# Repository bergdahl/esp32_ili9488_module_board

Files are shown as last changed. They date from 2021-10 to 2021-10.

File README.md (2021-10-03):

# esp32_ili9488_module_board

> This is a work in progress. 

This is a simple ESP32 based board for the _3.5" TFT SPI 480X320_ module. It is powered by 5V over a 
micro USB connector, and has footprints both for ESP-WROOM-32 and ESP_VROVER-32.

I designed the board primarily for use with [Dustin Watt's FreeTouchDeck firmware](https://github.com/DustinWatts/FreeTouchDeck).

Programming is done using an external FTDI232 board.

## PCB files

I have added the Gerber files in the `PCB/Gerber` folder, just zip and upload to your favorite PCB manufacturer.

I have also included the EAGLE design files if you need to modify the design for yoyr needs.

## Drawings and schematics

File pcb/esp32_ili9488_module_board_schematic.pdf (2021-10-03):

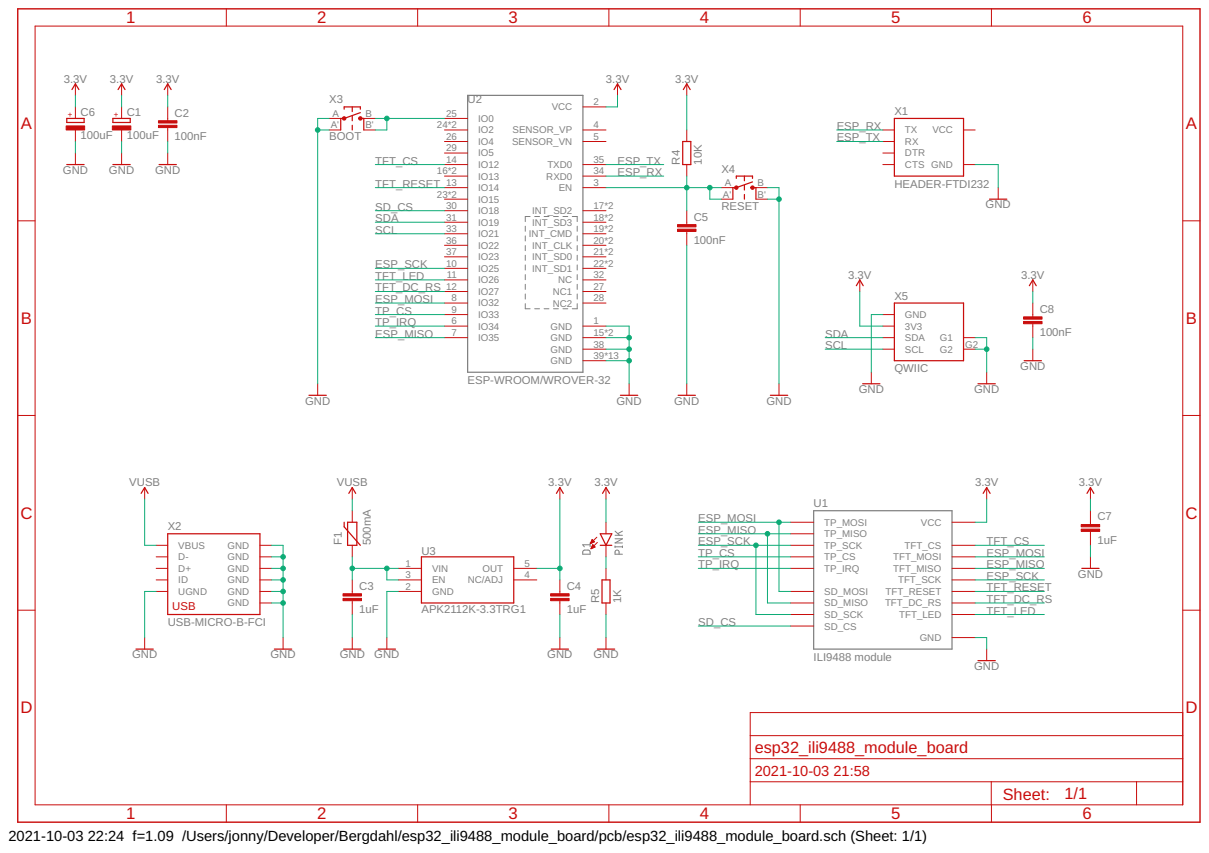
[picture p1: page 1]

2021-10-03 22:24 f=1.09 /Users/jonny/Developer/Bergdahl/esp32_ili9488_module_board/pcb/esp32_ili9488_module_board.sch (Sheet: 1/1)

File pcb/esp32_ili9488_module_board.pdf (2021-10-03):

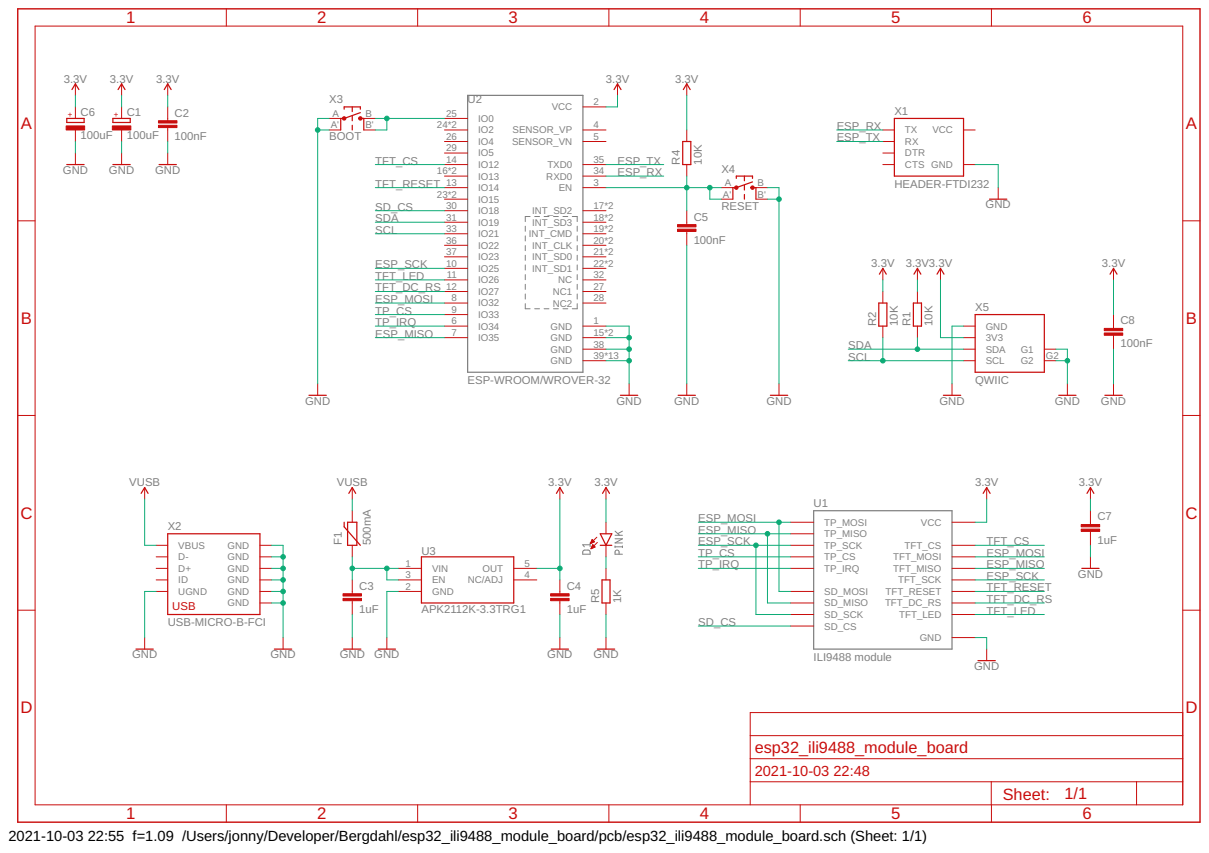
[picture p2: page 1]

2021-10-03 22:55 f=1.09 /Users/jonny/Developer/Bergdahl/esp32_ili9488_module_board/pcb/esp32_ili9488_module_board.sch (Sheet: 1/1)

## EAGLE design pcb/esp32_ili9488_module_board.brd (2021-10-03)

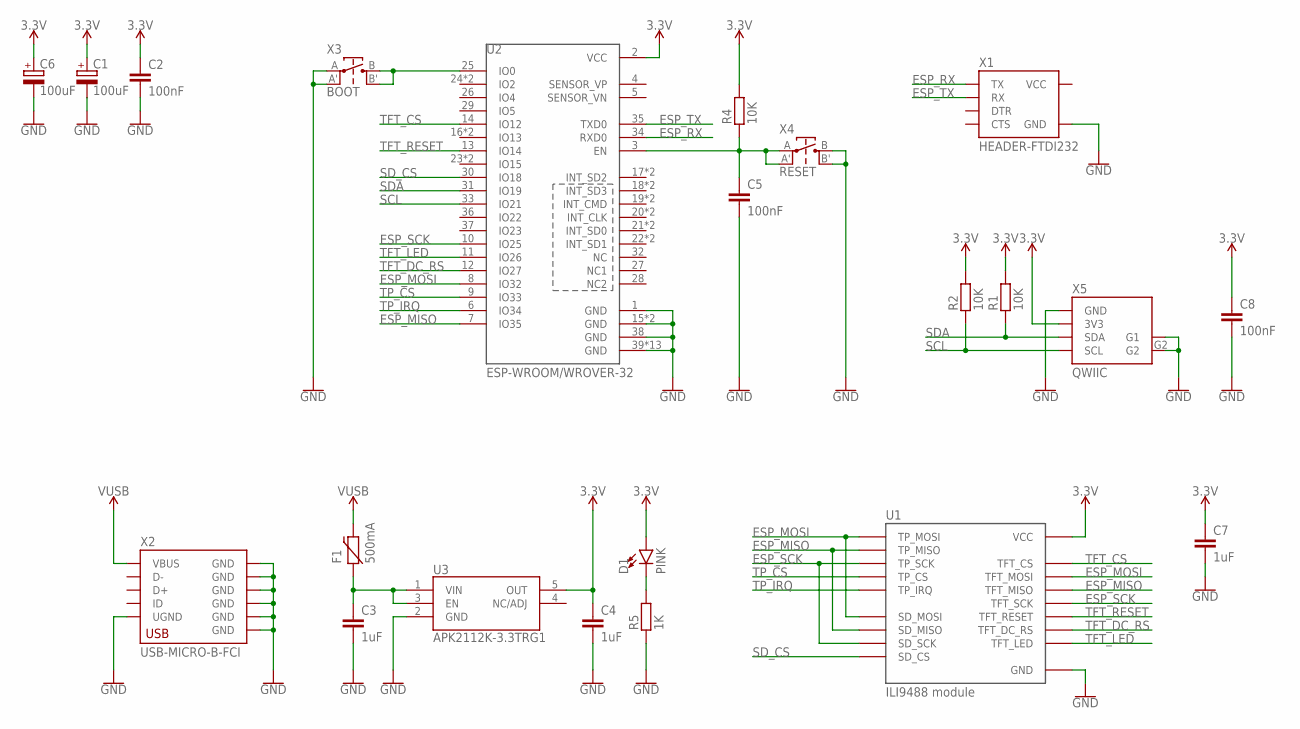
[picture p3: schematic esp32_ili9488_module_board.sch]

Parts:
C1, C6: 100uF; PANASONIC-SV-C
C2, C5, C8: 100nF; C0603
C3, C4, C7: 1uF; C0603
D1: PINK; LED0603
F1: 500mA; PTC-0ZCJ-1206
R1, R2, R4: 10K; R0603
R5: 1K; R0603
U1: ILI9488 module; TFT-ILI9488-MODULE
U2: ESP-WROOM/WROVER-32; ESP-WROOM_WROVER-32
U3: APK2112K-3.3TRG1; SOT23-5
X1: HEADER-FTDI232; FTDI232-1X06
X2: USB-MICRO-B-FCI
X3: BOOT; TACT-SWITCH-EVQ
X4: RESET; TACT-SWITCH-EVQ
X5: QWIIC; JST-SH-4-SMD-RA

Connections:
3.3V: C1.+, C2.1, C4.1, C6.+, C7.1, C8.1, D1.A, R1.2, R2.2, R4.2, U1.VCC, U2.2 (VCC), U3.5 (OUT), X5.3V3
ESP_MISO: U1.SD_MISO, U1.TFT_MISO, U1.TP_MISO, U2.7 (IO35)
ESP_MOSI: U1.SD_MOSI, U1.TFT_MOSI, U1.TP_MOSI, U2.8 (IO32)
ESP_RX: U2.34 (RXD0), X1.TX
ESP_SCK: U1.SD_SCK, U1.TFT_SCK, U1.TP_SCK, U2.10 (IO25)
ESP_TX: U2.35 (TXD0), X1.RX
GND: C1.-, C2.2, C3.2, C4.2, C5.2, C6.-, C7.2, C8.2, R5.1, U1.GND, U2.1 (GND), U2.15 (GND), U2.15_R (GND), U2.38 (GND), U2.39 (GND), U2.39V_1 (GND), U2.39V_2 (GND), U2.39V_3 (GND), U2.39V_4 (GND), U2.39V_5 (GND), U2.39V_6 (GND), U2.39V_7 (GND), U2.39V_8 (GND), U2.39V_9 (GND), U2.39V_10 (GND), U2.39V_12 (GND), U2.39V_13 (GND), U3.2 (GND), X1.GND, X2.5 (UGND), X2.GND@1 (GND), X2.GND@2 (GND), X2.GND@3 (GND), X2.GND@4 (GND), X2.GND@5 (GND), X2.GND@6 (GND), X3.A, X3.A', X4.B, X4.B', X5.G1, X5.G2, X5.GND
unnamed: C3.1, F1.1, U3.1 (VIN), U3.3 (EN)
unnamed: D1.C, R5.2
unnamed: C5.1, R4.1, U2.3 (EN), X4.A, X4.A'
unnamed: U2.25 (IO0), X3.B, X3.B'
SCL: R2.1, U2.33 (IO21), X5.SCL
SDA: R1.1, U2.31 (IO19), X5.SDA
SD_CS: U1.SD_CS, U2.30 (IO18)
TFT_CS: U1.TFT_CS, U2.14 (IO12)
TFT_DC_RS: U1.TFT_DC_RS, U2.12 (IO27)
TFT_LED: U1.TFT_LED, U2.11 (IO26)
TFT_RESET: U1.TFT_RESET, U2.13 (IO14)
TP_CS: U1.TP_CS, U2.9 (IO33)
TP_IRQ: U1.TP_IRQ, U2.6 (IO34)
VCC: X1.VCC
VUSB: F1.2, X2.1 (VBUS)

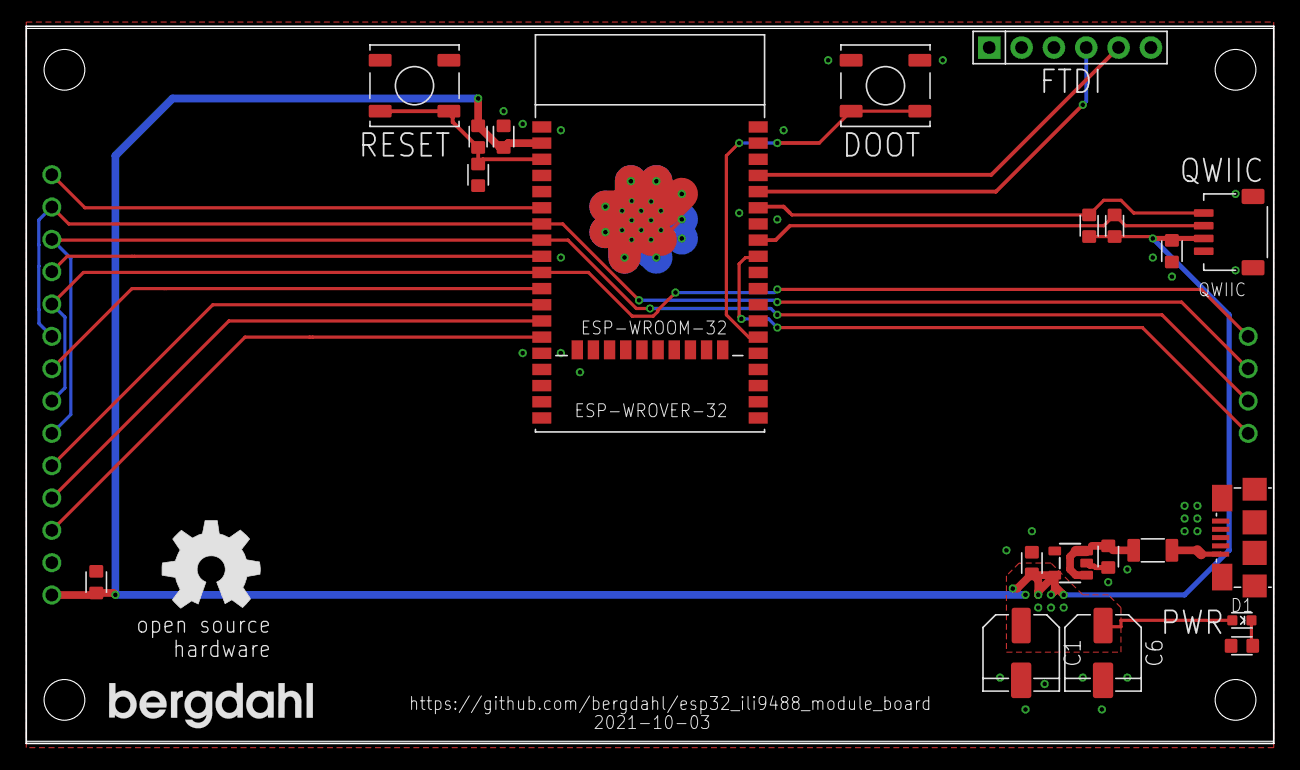
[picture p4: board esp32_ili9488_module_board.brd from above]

Board: 2 copper layers, 98.0 x 56.3 mm, 24 parts (1 on the bottom side), 21 nets.

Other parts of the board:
U$1: BERGDAHL-20MM-TPLACE
U$2: OSHW-8MM-TPLACE

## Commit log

2021-10-03 Added schematic PDF
2021-10-03 Add I2C pullups
    [esp32_ili9488_module_board.brd, esp32_ili9488_module_board.sch]
2021-10-03 Updated gerbers
    [esp32_ili9488_module_board.GTL, esp32_ili9488_module_board.GTO, esp32_ili9488_module_board.GTP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]
